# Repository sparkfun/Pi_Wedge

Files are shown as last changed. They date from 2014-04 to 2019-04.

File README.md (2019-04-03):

**NOTE:** *This product has been retired from our catalog. For the latest version, check out [BOB-13717](https://www.sparkfun.com/products/13717).*

*If you are looking for more up-to-date info, please check out some of these resources to see how other users are still hacking and improving on this version of the product.*
* *[SparkFun Forum](https://forum.sparkfun.com/)*
* *[Comments Here on GitHub](https://github.com/sparkfun/Pi_Wedge/issues)*
* *[IRC Channel](https://www.sparkfun.com/news/263)*

Pi Wedge - Breakout For Raspberry Pi GPIO Connector
----------------------------

Pi Wedge (https://www.sparkfun.com/products/retired/12652)

This is the Pi Wedge, a small board that connects to the Raspberry Pi’s 26-pin GPIO connector, and breaks the pins out to breadboard-friendly arrangement and spacing, and even adds a couple of decoupling capacitors on the power supply lines. The “Wedge” also makes the initial bringup process easier - you can plug an FTDI Basic module into the built-in serial port. Each Pi Wedge comes as an easy to assemble kit that can can be inserted into the Raspberry Pi’s GPIO port that allows you to prototype as soon as you are done soldering.

The kit works with both the [Model A](https://www.sparkfun.com/products/11837) and [Model B](https://www.sparkfun.com/products/11546) versions of the Raspberry Pi. 

It adapts the GPIO header on the Pi to a standard solderless breadboard, such as our [meduim](https://www.sparkfun.com/products/12002), [large](https://www.sparkfun.com/products/112) and [extra large](https://www.sparkfun.com/products/12614) breadboards.  While it will technically with with a [mini](https://www.sparkfun.com/products/12043) breadboard, it won't leave much room for external circuitry.

More information can be found on the [Pi Wedge product Page](https://www.sparkfun.com/products/12652), and in the [Pi Wedge hookup guide](https://learn.sparkfun.com/tutorials/236).

This part was created in Eagle v6.5.0.  Software examples were developed using the [WiringPi](wiringpi.com) libraries and utilities.

Repository Contents
-------------------

* **/Hardware** - All Eagle design files (.brd, .sch, .STL)
* **/Software** - C source code for SPI, I2C and GPIO examples.  All use [WiringPi](wiringpi.com) for the underlying device interfaces

Documentation
--------------
* **[Hookup Guide](https://learn.sparkfun.com/tutorials/236)** - Basic hookup guide.

Product Versions
----------------
* [ KIT-12652](https://www.sparkfun.com/products/12652)- Pi Wedge kit

Version History
---------------

* [24dd78154b](https://github.com/sparkfun/Pi_Wedge/commit/9d9670af0e99a6d3599a9afe51451999449d4cf8) PCB revision 1.2 

License Information
-------------------
The hardware is released under [Creative Commons ShareAlike 4.0 International](https://creativecommons.org/licenses/by-sa/4.0/).

The code is beerware; if you see me (or any other SparkFun employee) at the local, and you've found our code helpful, please buy us a round!

Distributed as-is; no warranty is given.

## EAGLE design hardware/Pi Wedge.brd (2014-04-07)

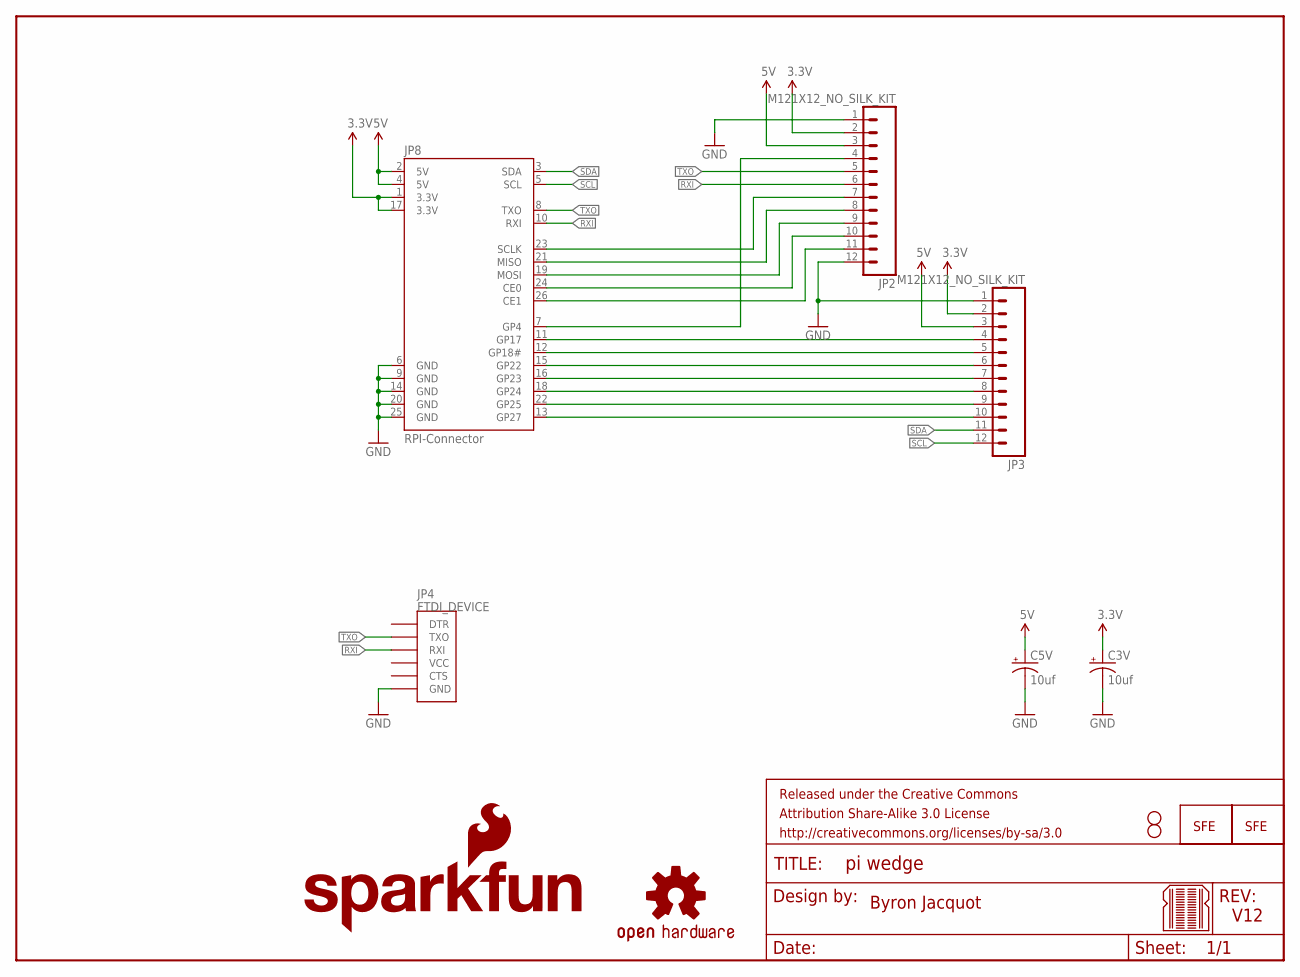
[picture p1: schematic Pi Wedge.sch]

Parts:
C3V, C5V: 10uf; CPOL-RADIAL-10UF-25V-KIT
FRAME2: FRAME-LETTER; CREATIVE_COMMONS
JP1, JP5: LOGO-SFESK; SFE-LOGO-FLAME
JP2, JP3: M121X12_NO_SILK_KIT; 1X12_NO_SILK_KIT
JP4: FTDI_DEVICE; FTDI_DEVICE_SIDE
JP8: RPI-Connector; 2X13-SHROUDED
LOGO1: SFE_LOGO_NAME_FLAME.2_INCH; SFE_LOGO_NAME_FLAME_.2
STANDOFF1, STANDOFF2: STAND-OFF
U$1: OSHW-LOGOS; OSHW-LOGO-S
U$2: BREADBOARD_PATTERN; BREADBOARD_SPACING

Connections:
3.3V: C3V.1 (+), JP2.2, JP3.2, JP8.1 (3.3V), JP8.17 (3.3V)
5V: C5V.1 (+), JP2.3, JP3.3, JP8.2 (5V), JP8.4 (5V)
CE0: JP2.10, JP8.24 (CE0)
CE1: JP2.11, JP8.26 (CE1)
GND: C3V.2 (-), C5V.2 (-), JP2.1, JP2.12, JP3.1, JP4.P$6 (GND), JP8.6 (GND), JP8.9 (GND), JP8.14 (GND), JP8.20 (GND), JP8.25 (GND)
GP4: JP2.4, JP8.7 (GP4)
GP17: JP3.4, JP8.11 (GP17)
GP18: JP3.5, JP8.12 (GP18#)
GP22: JP3.6, JP8.15 (GP22)
GP23: JP3.7, JP8.16 (GP23)
GP24: JP3.8, JP8.18 (GP24)
GP25: JP3.9, JP8.22 (GP25)
GP27: JP3.10, JP8.13 (GP27)
MISO: JP2.8, JP8.21 (MISO)
MOSI: JP2.9, JP8.19 (MOSI)
RXI: JP2.6, JP4.P$3 (RXI), JP8.10 (RXI)
SCL: JP3.12, JP8.5 (SCL)
SCLK: JP2.7, JP8.23 (SCLK)
SDA: JP3.11, JP8.3 (SDA)
TXO: JP2.5, JP4.P$2 (TXO), JP8.8 (TXO)

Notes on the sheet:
Byron Jacquot
V12

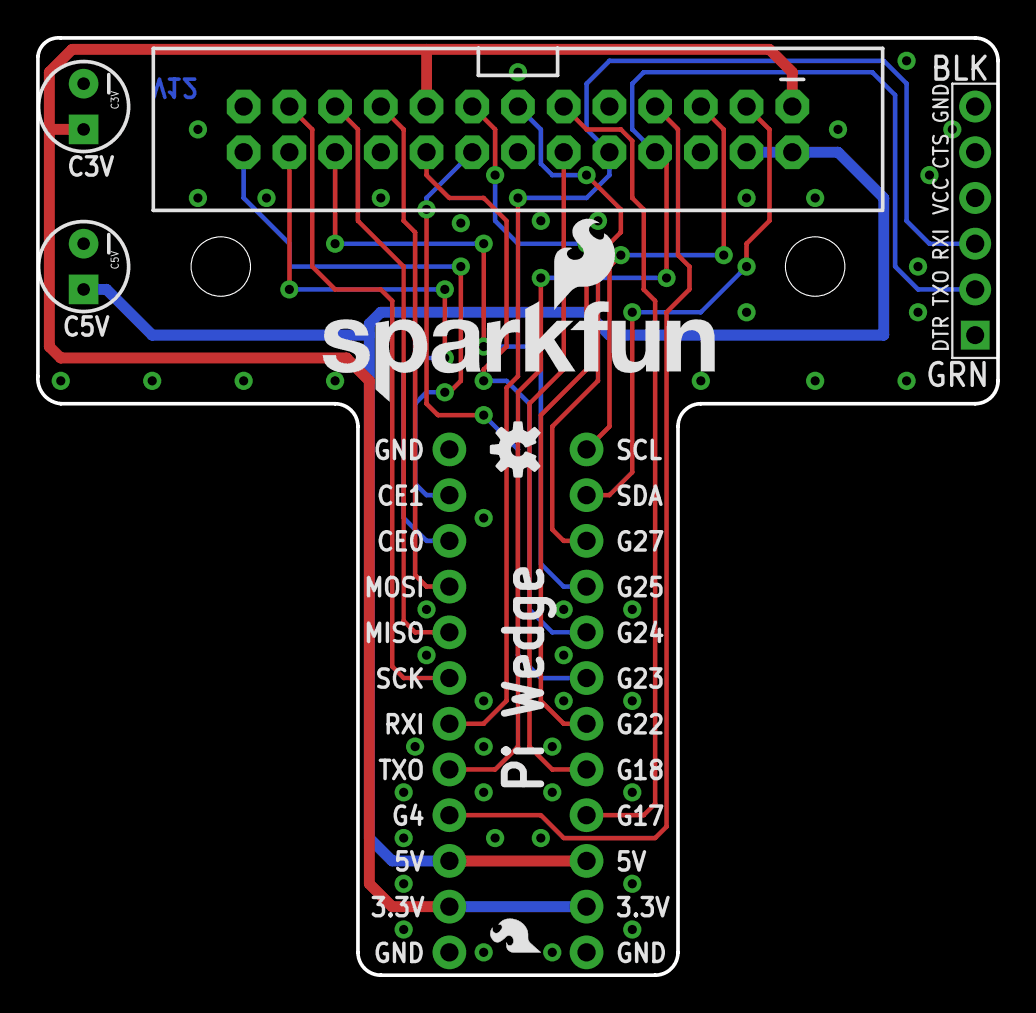
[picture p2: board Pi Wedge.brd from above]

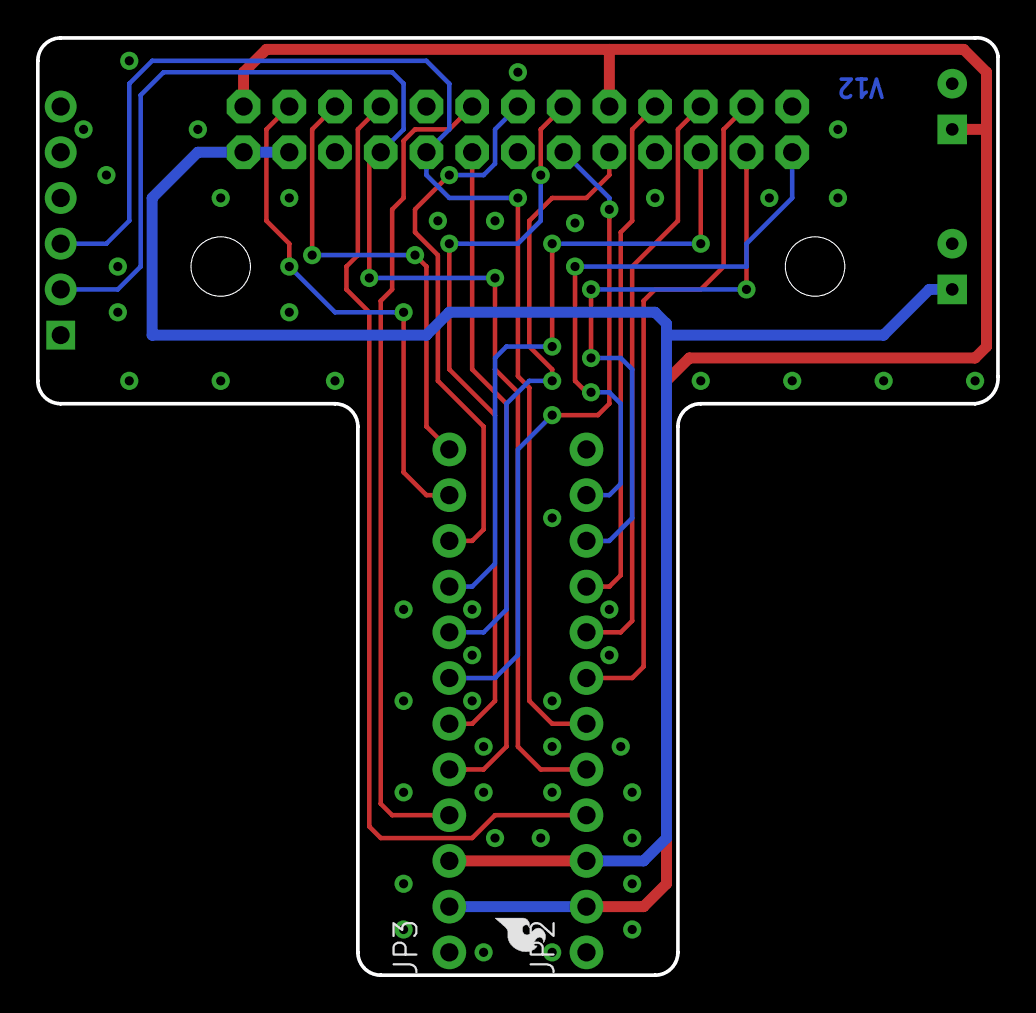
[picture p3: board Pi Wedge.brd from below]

Board: 2 copper layers, 53.3 x 52.1 mm, 14 parts (3 on the bottom side), 20 nets.

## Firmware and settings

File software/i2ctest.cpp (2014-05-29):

/******************************************************************************
i2ctest.cpp
Raspberry Pi I2C interface demo
Byron Jacquot @ SparkFun Electronics>
4/2/2014
https://github.com/sparkfun/Pi_Wedge

A brief demonstration of the Raspberry Pi I2C interface, using the SparkFun
Pi Wedge breakout board.

Resources:

This example makes use of the Wiring Pi library, which streamlines the interface
the the I/O pins on the Raspberry Pi, providing an API that is similar to the
Arduino.  You can learn about installing Wiring Pi here:
http://wiringpi.com/download-and-install/

The I2C API is documented here:
https://projects.drogon.net/raspberry-pi/wiringpi/i2c-library/

The init call returns a standard file descriptor.  More detailed configuration
of the interface can be performed using ioctl calls on that descriptor.
See the wiringPi I2C implementation (wiringPi/wiringPiI2C.c) for some examples.
Parameters configurable with ioctl are documented here:
http://git.kernel.org/cgit/linux/kernel/git/torvalds/linux.git/tree/Documentation/i2c/dev-interface

Hardware connections:

This file interfaces with the SparkFun MCP4725 breakout board:
https://www.sparkfun.com/products/8736

The board was connected as follows:
(Raspberry Pi)(MCP4725)
GND  -> GND
3.3V -> Vcc
SCL  -> SCL
SDA  -> SDA

An oscilloscope probe was connected to the analog output pin of the MCP4725.

To build this file, I use the command:
>  g++ i2ctest.cpp -lwiringPi

Then to run it, first the I2C kernel module needs to be loaded.  This can be 
done using the GPIO utility.
> gpio load i2c 400
> ./a.out

This will run the MCP through it's output range several times.  A rising 
sawtooth will be seen on the analog output.

Development environment specifics:
Tested on Raspberry Pi V2 hardware, running Raspbian.
Building with GCC 4.6.3 (Debian 4.6.3-14+rpi1)

This code is beerware; if you see me (or any other SparkFun employee) at the
local, and you've found our code helpful, please buy us a round!

Distributed as-is; no warranty is given.
******************************************************************************/

#include <iostream>
#include <errno.h>
#include <wiringPiI2C.h>

using namespace std;

int main()
{
   int fd, result;

   // Initialize the interface by giving it an external device ID.
   // The MCP4725 defaults to address 0x60.   
   //
   // It returns a standard file descriptor.
   // 
   fd = wiringPiI2CSetup(0x60);

   cout << "Init result: "<< fd << endl;

   for(int i = 0; i < 0x0000ffff; i++)
   {
      // I tried using the "fast write" command, but couldn't get it to work.  
      // It's not entirely obvious what's happening behind the scenes as
      // regards to endianness or length of data sent.  I think it's only 
      // sending one byte, when we really need two.
      //
      // So instead I'm doing a 16 bit register access.  It appears to 
      // properly handle the endianness, and the length is specified by the 
      // call.  The only question was the register address, which is the 
      // concatenation of the command (010x = write DAC output) 
      // and power down (x00x = power up) bits.
      result = wiringPiI2CWriteReg16(fd, 0x40, (i & 0xfff) );
      
      if(result == -1)
      {
         cout << "Error.  Errno is: " << errno << endl;
      }
   }
}

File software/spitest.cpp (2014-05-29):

/******************************************************************************
i2ctest.cpp
Raspberry Pi I2C interface demo
Byron Jacquot @ SparkFun Electronics>
4/2/2014
https://github.com/sparkfun/Pi_Wedge

A brief demonstration of the Raspberry Pi I2C interface, using the SparkFun
Pi Wedge breakout board.

Resources:

This example makes use of the Wiring Pi library, which streamlines the interface
to the the I/O pins on the Raspberry Pi, providing an API that is similar to the
Arduino.  You can learn about installing Wiring Pi here:
http://wiringpi.com/download-and-install/

The wiringPi SPI API is documented here:
https://projects.drogon.net/raspberry-pi/wiringpi/spi-library/

The init call returns a standard file descriptor.  More detailed configuration
of the interface can be performed using ioctl calls on that descriptor.
See the wiringPi SPI implementation (wiringPi/wiringPiSPI.c) for some examples.
Parameters configurable with ioctl are documented here:
http://git.kernel.org/cgit/linux/kernel/git/torvalds/linux.git/tree/Documentation/spi/spidev

Hardware connections:

This file interfaces with the SparkFun Serial 7 Segment display:
https://www.sparkfun.com/products/11629

The board was connected as follows:
(Raspberry Pi)(Serial 7 Segment)
GND  -> GND
3.3V -> Vcc
CE1  -> SS (Shift Select)
SCK  -> SCK 
MOSI -> SDI
MISO -> SDO

To build this file, I use the command:
>  g++ spitest.cpp -lwiringPi

Then to run it, first the spi kernel module needs to be loaded.  This can be 
done using the GPIO utility.
> gpio load spi
> ./a.out

This test uses the single-segment mode of the 7 segment display.  It shifts a 
bit through the display characters, lighting a single character of each at a 
time.

Development environment specifics:
Tested on Raspberry Pi V2 hardware, running Raspbian.
Building with GCC 4.6.3 (Debian 4.6.3-14+rpi1)

This code is beerware; if you see me (or any other SparkFun employee) at the
local, and you've found our code helpful, please buy us a round!

Distributed as-is; no warranty is given.
******************************************************************************/

#include <iostream>
#include <errno.h>
#include <wiringPiSPI.h>

using namespace std;

// channel is the wiringPi name for the chip select (or chip enable) pin.
// Set this to 0 or 1, depending on how it's connected.
static const int CHANNEL = 1;

int main()
{
   int fd, result;
   unsigned char buffer[100];

   cout << "Initializing" << endl ;

   // Configure the interface.
   // CHANNEL insicates chip select,
   // 500000 indicates bus speed.
   fd = wiringPiSPISetup(CHANNEL, 500000);

   cout << "Init result: " << fd << endl;

   // clear display
   buffer[0] = 0x76;
   wiringPiSPIDataRW(CHANNEL, buffer, 1);

   sleep(5);

   // Do a one-hot bit selection for each field of the display
   // It displays gibberish, but tells us that we're correctly addressing all 
   // of the segments.
   for(int i = 1; i <= 0x7f; i <<= 1)
   {
      // the decimals, colon and apostrophe dots
      buffer[0] = 0x77;
      buffer[1] = i;
      result = wiringPiSPIDataRW(CHANNEL, buffer, 2);
      
      // The first character
      buffer[0] = 0x7b;
      buffer[1] = i;
      result = wiringPiSPIDataRW(CHANNEL, buffer, 2);
      
      // The second character
      buffer[0] = 0x7c;
      buffer[1] = i;
      result = wiringPiSPIDataRW(CHANNEL, buffer, 2);
      
      // The third character
      buffer[0] = 0x7d;
      buffer[1] = i;
      result = wiringPiSPIDataRW(CHANNEL, buffer, 2);

      // The last character
      buffer[0] = 0x7e;
      buffer[1] = i;
      result = wiringPiSPIDataRW(CHANNEL, buffer, 2);

      // Pause so we can see them
      sleep(5);
   }

   // clear display again
   buffer[0] = 0x76;
   wiringPiSPIDataRW(CHANNEL, buffer, 1);

}

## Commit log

2013-11-15 Correcting footprint
    The front and back rows needed to be swapped to work with the SparkFun
    23 pin ribbon.
    [Pi Wedge.brd, Pi Wedge.sch]
2013-11-20 Adjusting everything.
    Reoriented connectors, added 6-pin FTDI header and extra access to power
    and ground.
    [Pi Wedge.brd, Pi Wedge.sch]
2013-11-21 Fixing keepout violations around mtg holes
    [Pi Wedge.brd]
2013-11-21 Updates based on group review
    Including:
    -Kit footprints for the DIP-spaced headers
    -Wider overall spacing, so power pads match a breadboard more closely
    -PTH decoupling caps on power lines
    -Rounded corners.
    -Vector text
    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
    [Pi Wedge.brd, Pi Wedge.sch]
2013-11-21 Touchup to Cap names
    [Pi Wedge.brd, Pi Wedge.sch]
2013-12-04 v1.1: Fixing airwire in ground pour.
    [Pi Wedge.brd]
2013-12-09 Moving vias from under silk.
    [Pi Wedge.brd]
2014-03-04 V1.2: Design revisions.
    Removing separate 5V and 3.3V connectors.
    Integrating 3.3V and 5V in both sides of the DIP-footprint area.
    Fixing swapped Tx/Rx on FTDI connector.
    [Pi Wedge.brd, Pi Wedge.sch]
2014-04-03 Adding software examples
    Using wiringPi to demonstrate C applications that access GPIO, SPI and
    I2C.
2014-04-07 Swapping in new breadboard reference symbol.
    No changes to the board itself.
    [Pi Wedge.brd, Pi Wedge.sch]
2014-05-29 Updates before making public.
    README and LICENSE both up to date.
    A few typos in the software were corrected.
    [i2ctest.cpp, spitest.cpp]

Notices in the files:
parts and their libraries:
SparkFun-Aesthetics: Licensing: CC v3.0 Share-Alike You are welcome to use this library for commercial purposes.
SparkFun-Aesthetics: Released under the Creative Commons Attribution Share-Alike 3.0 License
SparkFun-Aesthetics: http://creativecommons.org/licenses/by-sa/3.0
